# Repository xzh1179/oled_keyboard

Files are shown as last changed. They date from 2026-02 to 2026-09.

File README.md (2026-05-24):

# OLED Keyboard

A custom mechanical keyboard project featuring per-key OLED displays for dynamic legends, status information, and highly personalized layouts.

## Overview

OLED Keyboard is an experimental custom keyboard platform where each key can display its own icon, label, layer state, shortcut, or custom graphics.  
The goal of this project is to explore the intersection of keyboard design, multi-panel display integration, power distribution, and user interaction.

This project combines:

- custom PCB design
- embedded firmware development
- OLED display integration
- keyboard matrix scanning
- USB communication
- dynamic key rendering

Depending on the firmware mode, each key can show:

- key labels
- shortcuts
- symbols
- macros
- layer indicators
- application-specific legends
- simple animations or status feedback

## Motivation

Traditional keyboards are static: the legend printed on a keycap never changes.  
This project explores a more flexible and expressive approach where each key can adapt visually to:

- active layer
- language layout
- software context
- macro profile
- user preferences

The idea is to make a keyboard that is not only functional, but also programmable, informative, and visually unique.

## Features

- Per-key OLED displays
- Fully custom PCB
- Mechanical key switches
- Dynamic legends and layer indication
- Custom embedded firmware
- USB connectivity
- Macro and shortcut support
- Potential support for animations and contextual UI

## Hardware

Current hardware exploration includes:

- microcontroller: RP2040 
- OLED display 0.64inch 64x64 pixels, RGB color, based on SSD1357 controller 
- keyboard matrix scanning
- Kailh Choc V1 mechanical switch
- power distribution for many small displays
- SPI display communication
- optional rotary encoder support
- USB interface

> The exact hardware architecture may evolve as the project progresses.

## Architecture

The project is roughly divided into the following blocks:

1. **Keyboard matrix**  
   Detects key presses using rows and columns.

2. **Display subsystem**  
   Drives the OLED displays and refreshes per-key content.

3. **Firmware layer engine**  
   Handles keymaps, layers, macros, and display content generation.

4. **USB HID interface**  
   Sends keyboard events to the host computer.

5. **Power management**  
   Ensures stable power delivery for the MCU, switches, and all displays.

## Challenges

This project involves several interesting engineering challenges:

- driving many OLED displays efficiently
- balancing refresh rate and power consumption
- routing high-density display interconnects on PCB while keeping the layout compact, especially do not create too large space between two keys
- scaling SPI/I2C buses
- memory usage for icons/fonts/framebuffers
- firmware architecture for real-time input + rendering
- mechanical integration and assembly

## Project Status

This project is currently in active development.

Current focus areas include:

- hardware architecture exploration
- PCB design
- display driving strategy
- firmware prototyping
- validation of power and signal integrity constraints

## Repository Structure

```text
.
├── docs/            # Design notes, architecture, ideas, references
├── hardware/        # Schematics, PCB files, manufacturing outputs
├── firmware/        # Embedded firmware source code
├── images/          # Photos, renders, screenshots, diagrams
├── tools/           # Helper scripts, generators, utilities
└── README.md
```

## Assembly
The initial assembly of the keyboard is shown in the two figures below. At this stage, only one screen and one mechanical switch were mounted 
in order to validate the basic functionalities before proceeding with the soldering of the remaining components.

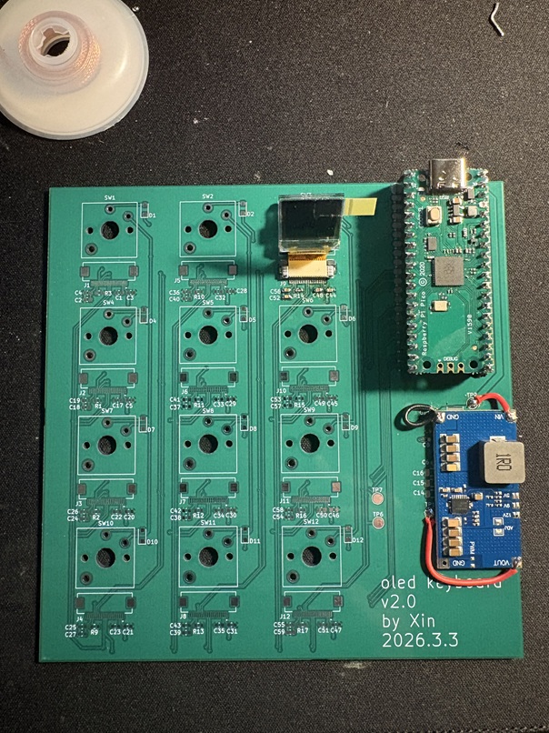
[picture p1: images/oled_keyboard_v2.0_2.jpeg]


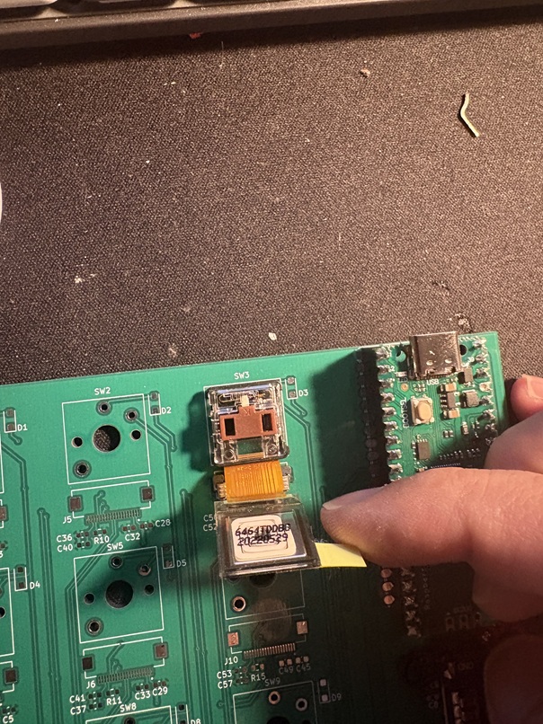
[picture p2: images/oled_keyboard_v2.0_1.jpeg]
 

Initial assembly has been completed. Functional testing will be conducted in the next stage.

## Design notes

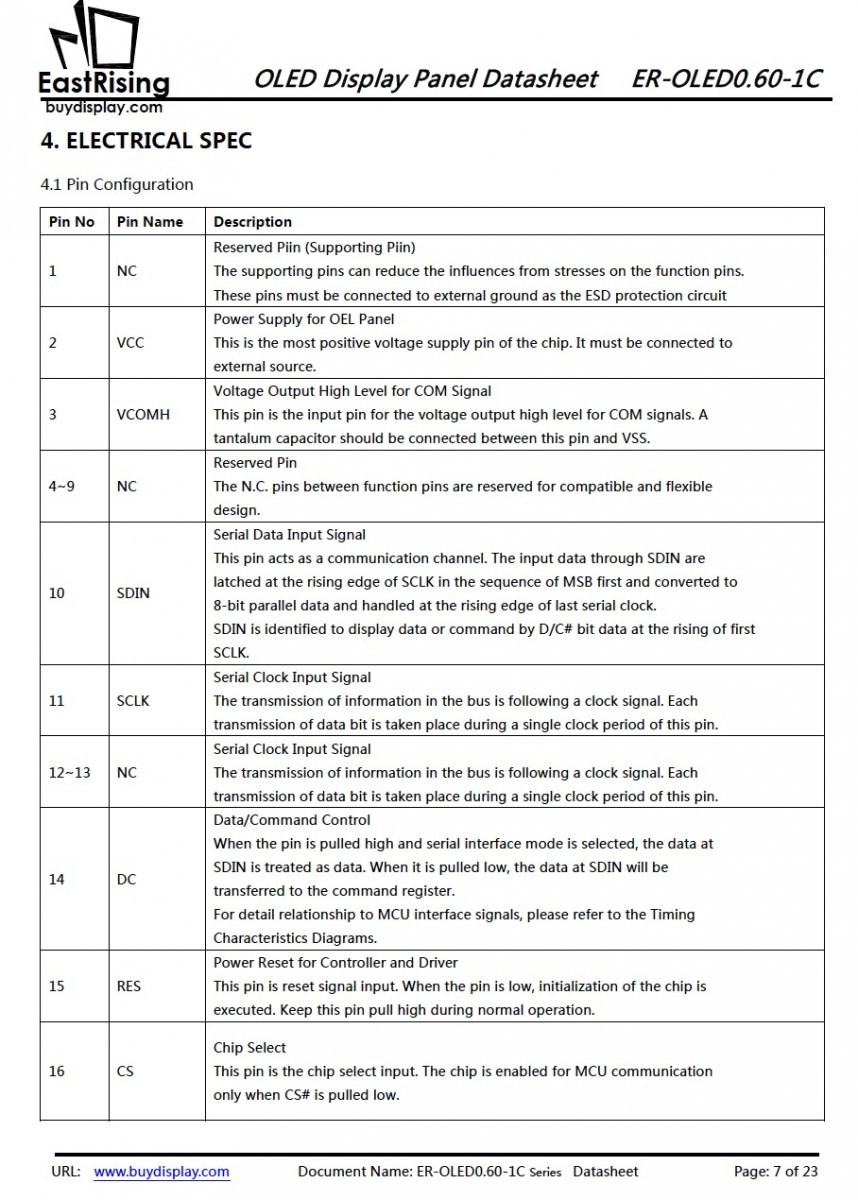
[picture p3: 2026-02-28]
doc/Screenshot 2024-11-09 at 2.21.43 AM.jpg

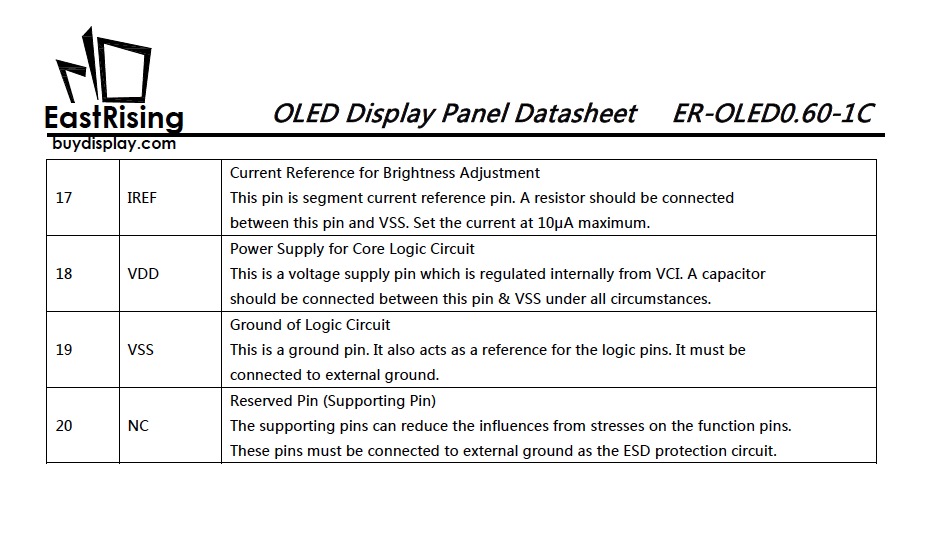
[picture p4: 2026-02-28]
doc/Screenshot 2024-11-09 at 2.21.47 AM.jpg

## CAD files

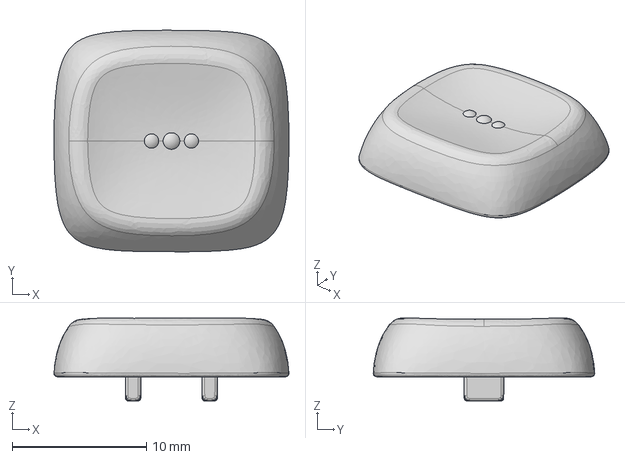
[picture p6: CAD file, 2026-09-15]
Choc_Stem_Choc_Size_Normal_Homing.step
17.5 x 16.5 x 6.17 mm

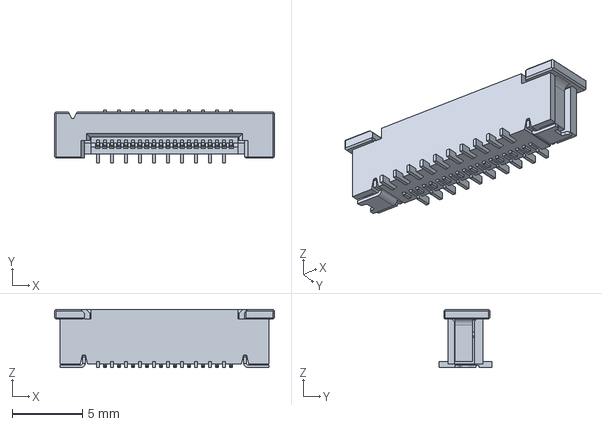
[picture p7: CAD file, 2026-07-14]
components/20pin_conn_vert/2-1734742-0.step
15.7 x 3.80 x 4.15 mm

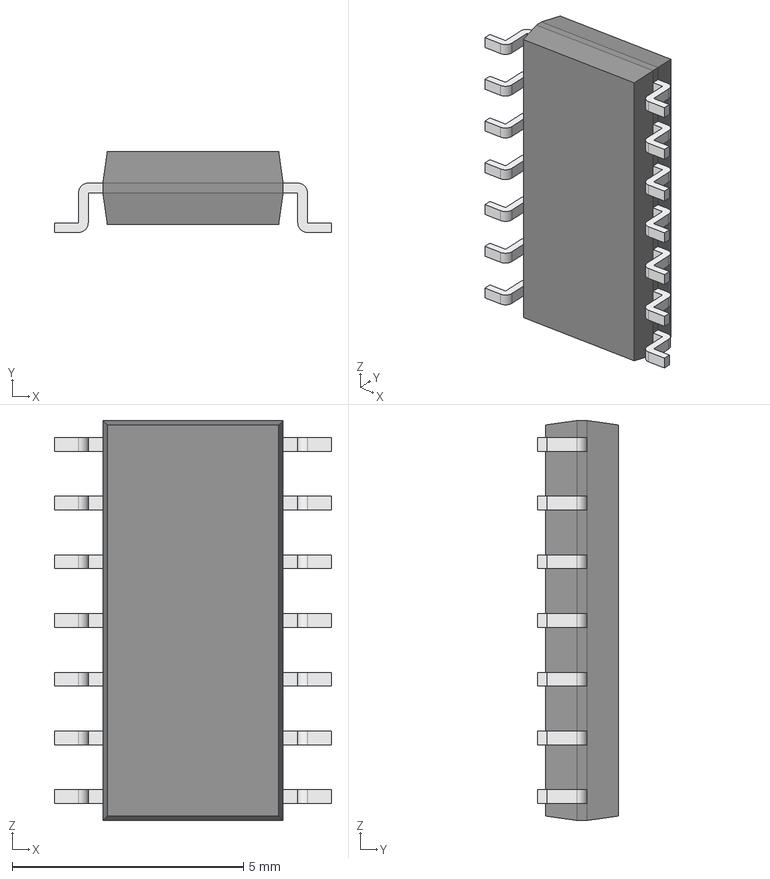
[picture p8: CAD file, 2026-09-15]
components/SN74LVC125ADTG4/SN74LVC125ADTG4.step
6.00 x 1.75 x 8.65 mm
Body001 (Mirror #1) x 7
XY-plane x 12
X-axis x 12

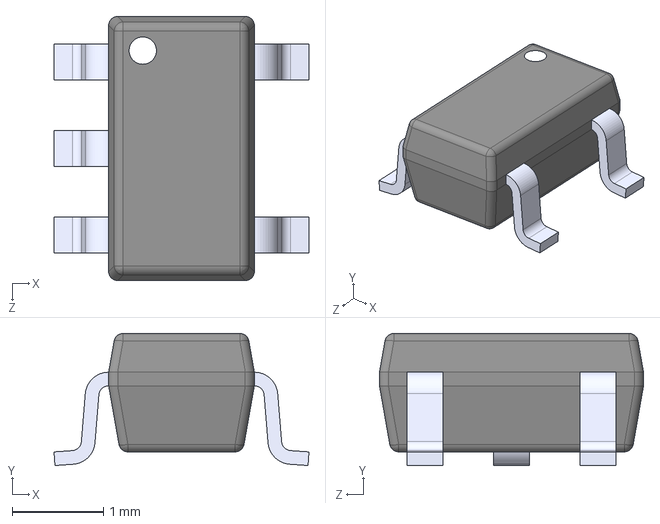
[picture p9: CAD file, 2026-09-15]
components/SN74LVC1G125DBVT/SN74LVC1G125DBVT.step
2.80 x 1.45 x 2.90 mm

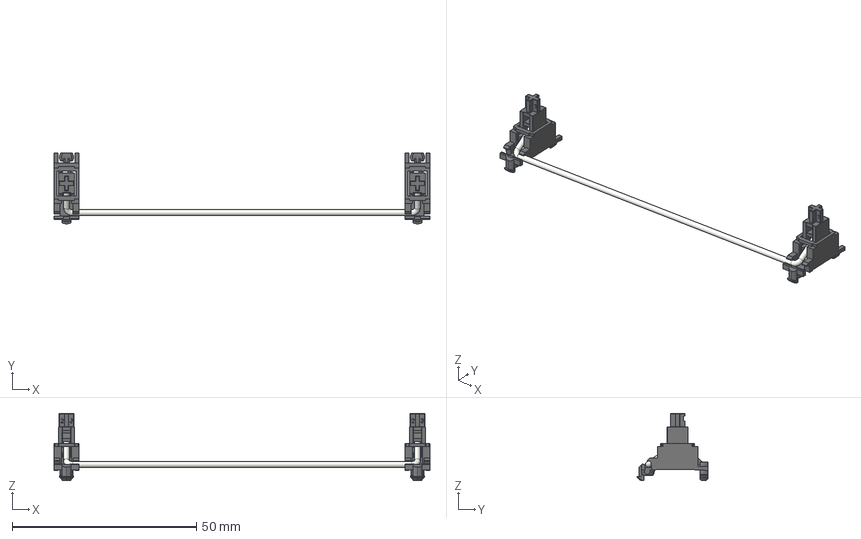
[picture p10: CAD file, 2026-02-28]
kiswitch-main/kiswitch-main/source_3d/Mounting_Keyboard_Stabilizer/Stabilizer_Cherry_MX_6u.FCStd
102.1 x 19.2 x 18.3 mm
Bar
Stabilizer_Key_
Stabilizer_Base_
Stabilizer_Key
Stabilizer_Base

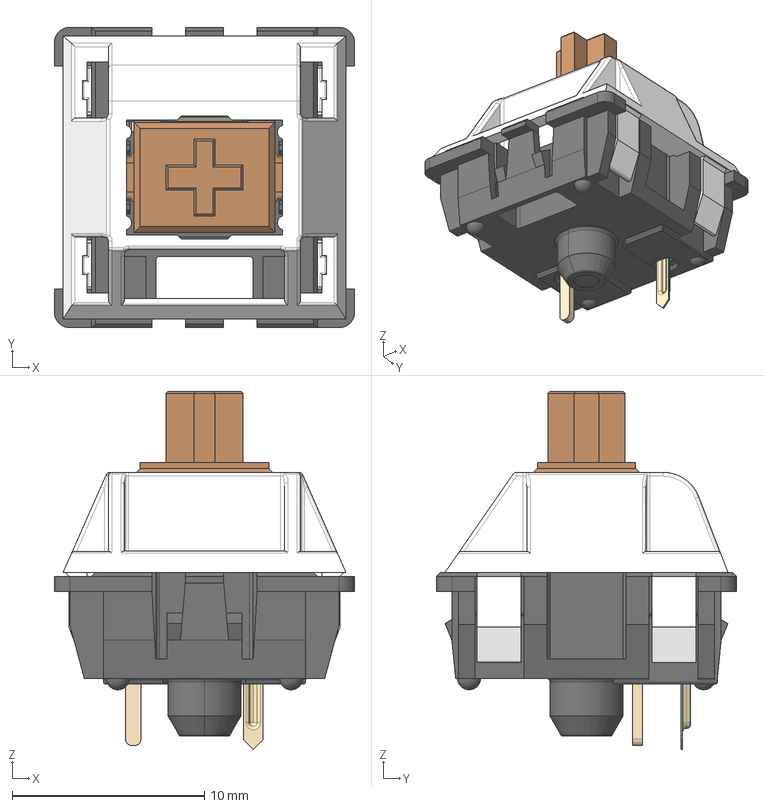
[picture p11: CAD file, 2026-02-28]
kiswitch-main/kiswitch-main/source_3d/Switch_Keyboard_Cherry_MX/SW_Cherry_MX_Plate.FCStd
15.6 x 15.6 x 18.6 mm
Lower_Housing
Upper_Housing
Stem
Pin_1
Pin_2
Spring
Clicker

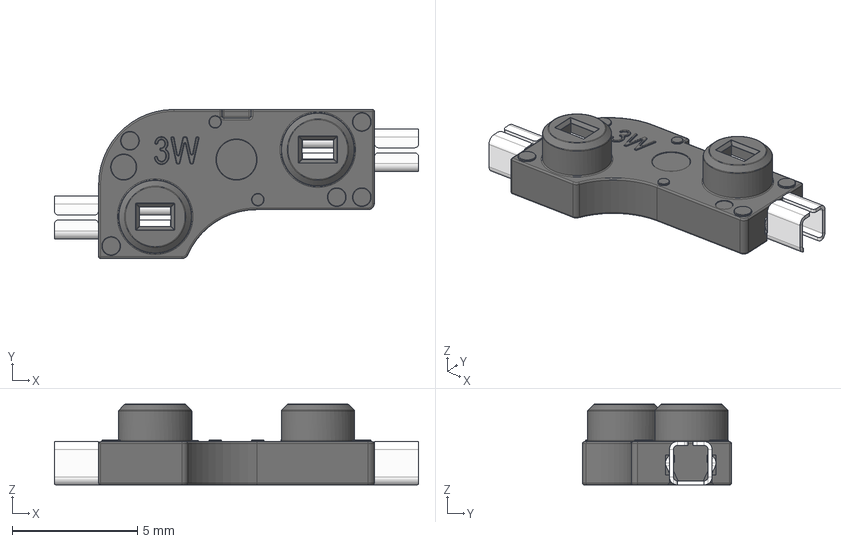
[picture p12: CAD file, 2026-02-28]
kiswitch-main/kiswitch-main/source_3d/Switch_Keyboard_Kailh/SW_Hotswap_Kailh.FCStd
14.5 x 5.95 x 3.22 mm
Pin_1
Pin_2
Plastic

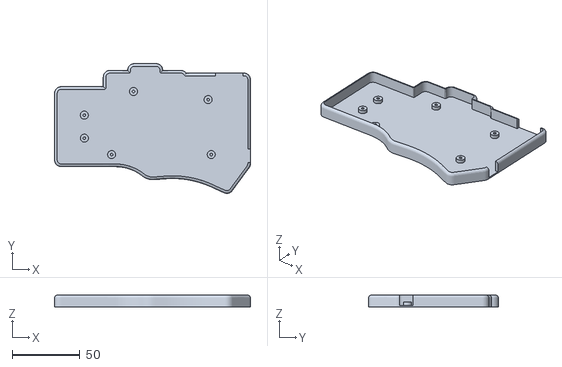
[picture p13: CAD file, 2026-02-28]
samples/piantor/piantor-main/case/bottom.stl
144.8 x 95.9 x 8.60

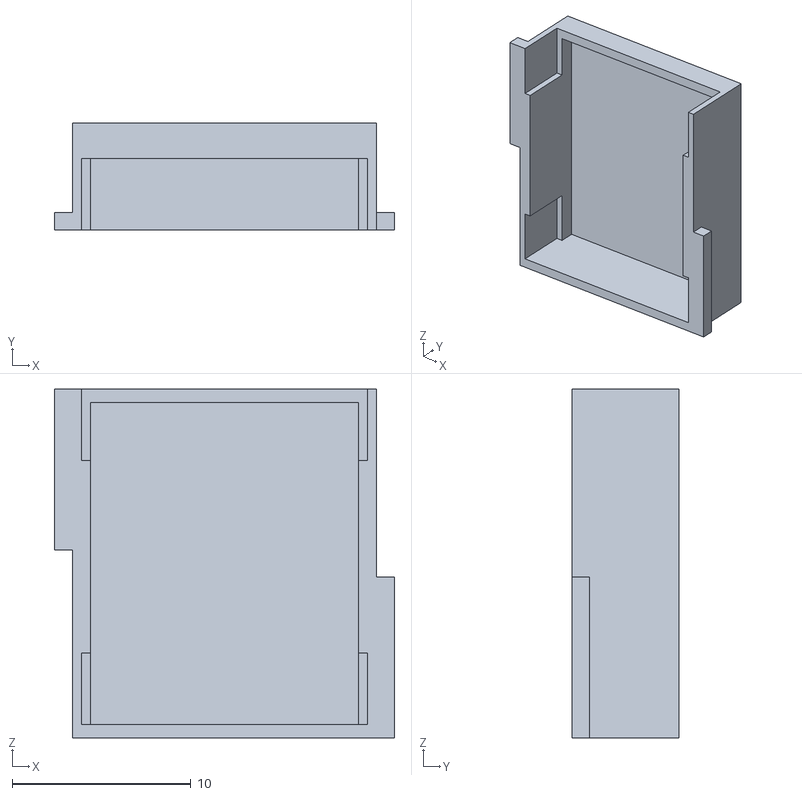
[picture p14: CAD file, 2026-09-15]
shell/shell - key-1.STL
19.0 x 6.00 x 19.5

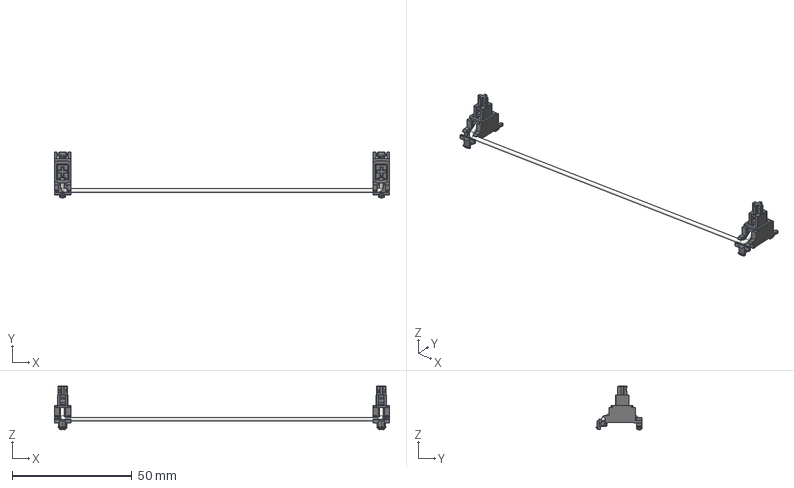
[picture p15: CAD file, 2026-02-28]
kiswitch-main/kiswitch-main/source_3d/Mounting_Keyboard_Stabilizer/Stabilizer_Cherry_MX_8u.FCStd
140.1 x 19.2 x 18.3 mm
Bar
Stabilizer_Key_
Stabilizer_Base_
Stabilizer_Key
Stabilizer_Base

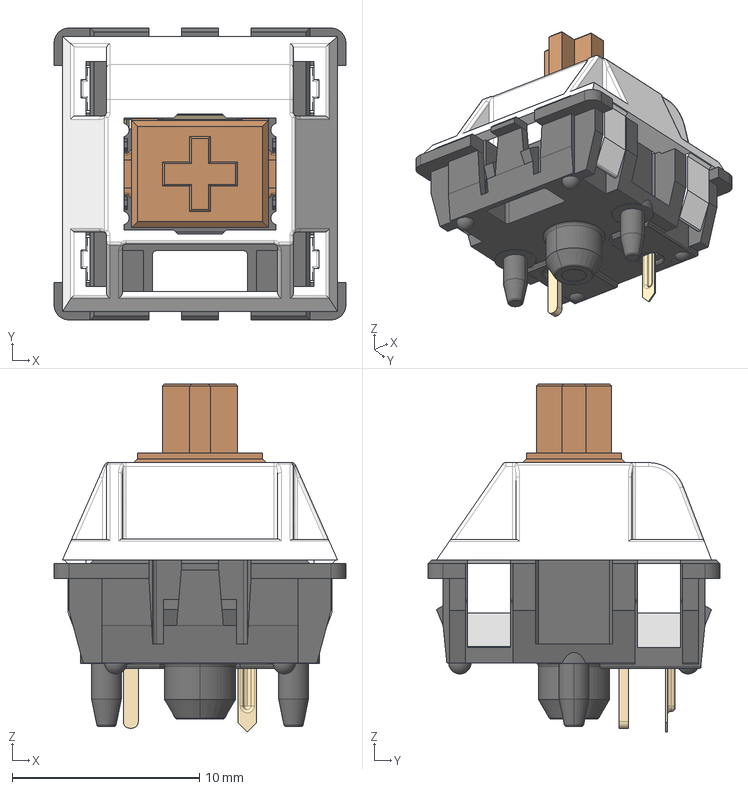
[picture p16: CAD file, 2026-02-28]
kiswitch-main/kiswitch-main/source_3d/Switch_Keyboard_Cherry_MX/SW_Cherry_MX_PCB.FCStd
15.6 x 15.6 x 18.6 mm
Lower_Housing
Upper_Housing
Stem
Pin_1
Pin_2
Spring
Clicker

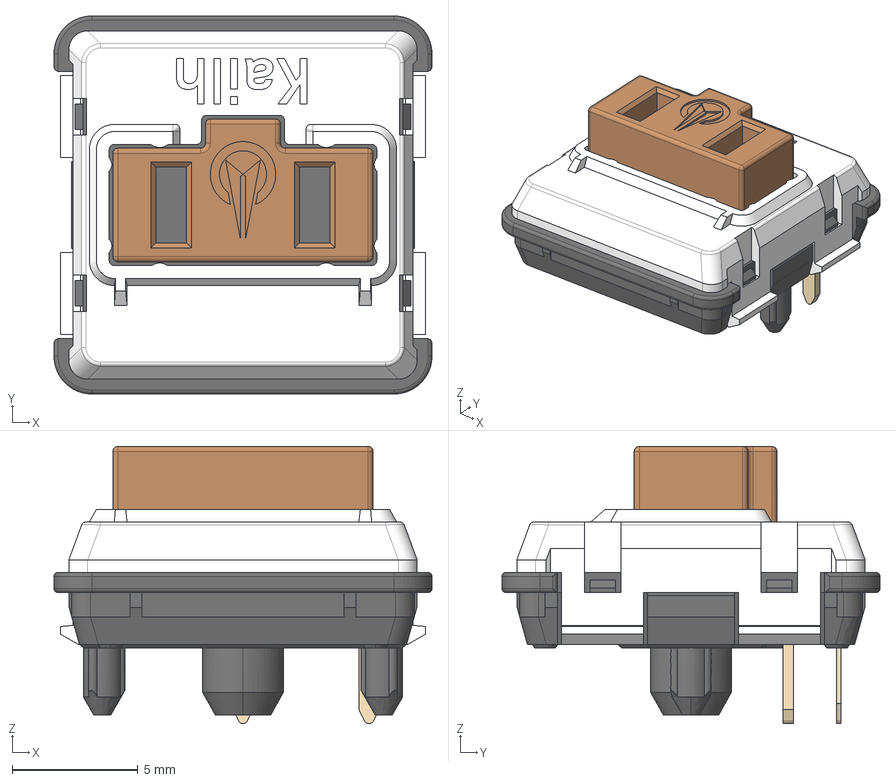
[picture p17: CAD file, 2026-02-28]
kiswitch-main/kiswitch-main/source_3d/Switch_Keyboard_Kailh/SW_Kailh_Choc_V1.FCStd
15.0 x 15.0 x 11.0 mm
Upper_Housing
Lower_Housing
Stem
Pin_2
Pin_1

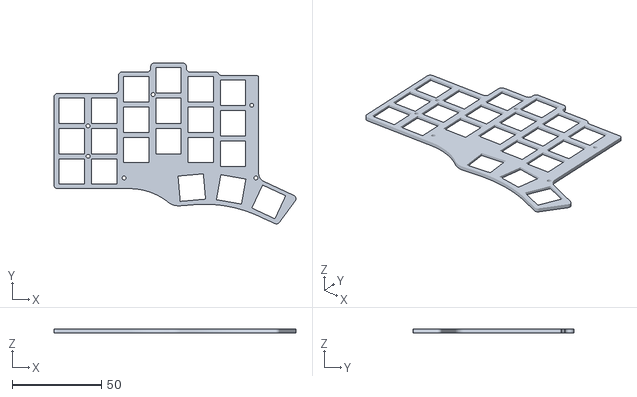
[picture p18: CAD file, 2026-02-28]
samples/piantor/piantor-main/case/switch-plate.stl
135.2 x 89.9 x 2.00

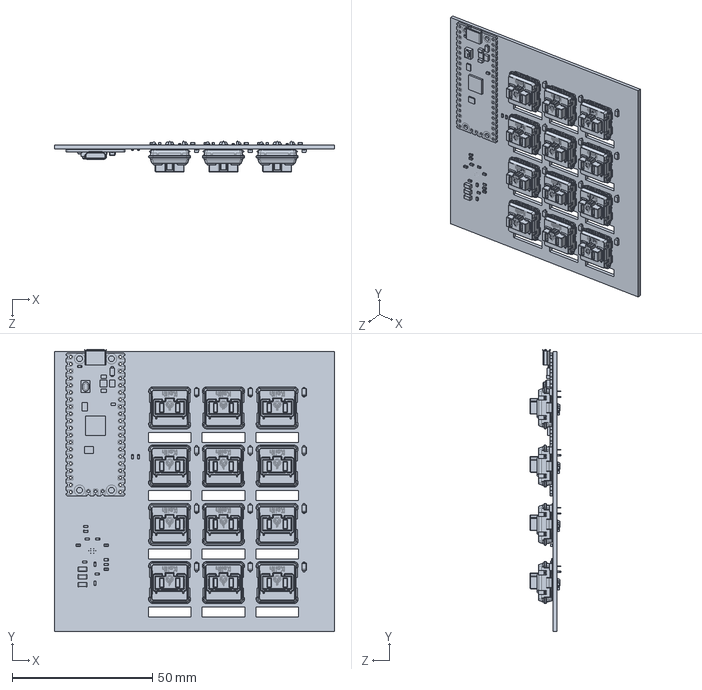
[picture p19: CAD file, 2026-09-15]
shell/pcb.SLDPRT
100.0 x 100.8 x 11.0 mm

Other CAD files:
shell/Assem1.SLDASM
kiswitch-main/kiswitch-main/source_3d/Mounting_Keyboard_Stabilizer/Stabilizer_Cherry_MX_7u.FCStd
kiswitch-main/kiswitch-main/source_3d/Switch_Keyboard_Kailh/SW_Hotswap_Kailh_Choc_v1.FCStd
shell/cover.SLDPRT
components/tps61088/TPS61088RHLR.step
kiswitch-main/kiswitch-main/source_3d/Mounting_Keyboard_Stabilizer/Stabilizer_Cherry_MX_2u.FCStd
kiswitch-main/kiswitch-main/source_3d/Mounting_Keyboard_Stabilizer/Stabilizer_Cherry_MX_3u.FCStd
kiswitch-main/kiswitch-main/source_3d/Mounting_Keyboard_Stabilizer/Stabilizer_Cherry_MX_6.25u.FCStd
shell/bottom.SLDPRT
shell/display_support.SLDPRT
shell/display_support.STL
shell/key.SLDPRT
shell/oled_keyboard.SLDASM
shell/oled_keyboard.step
shell/shell - cover-1 - bottom-1.STL
shell/shell - cover-1 - cover-1.STL

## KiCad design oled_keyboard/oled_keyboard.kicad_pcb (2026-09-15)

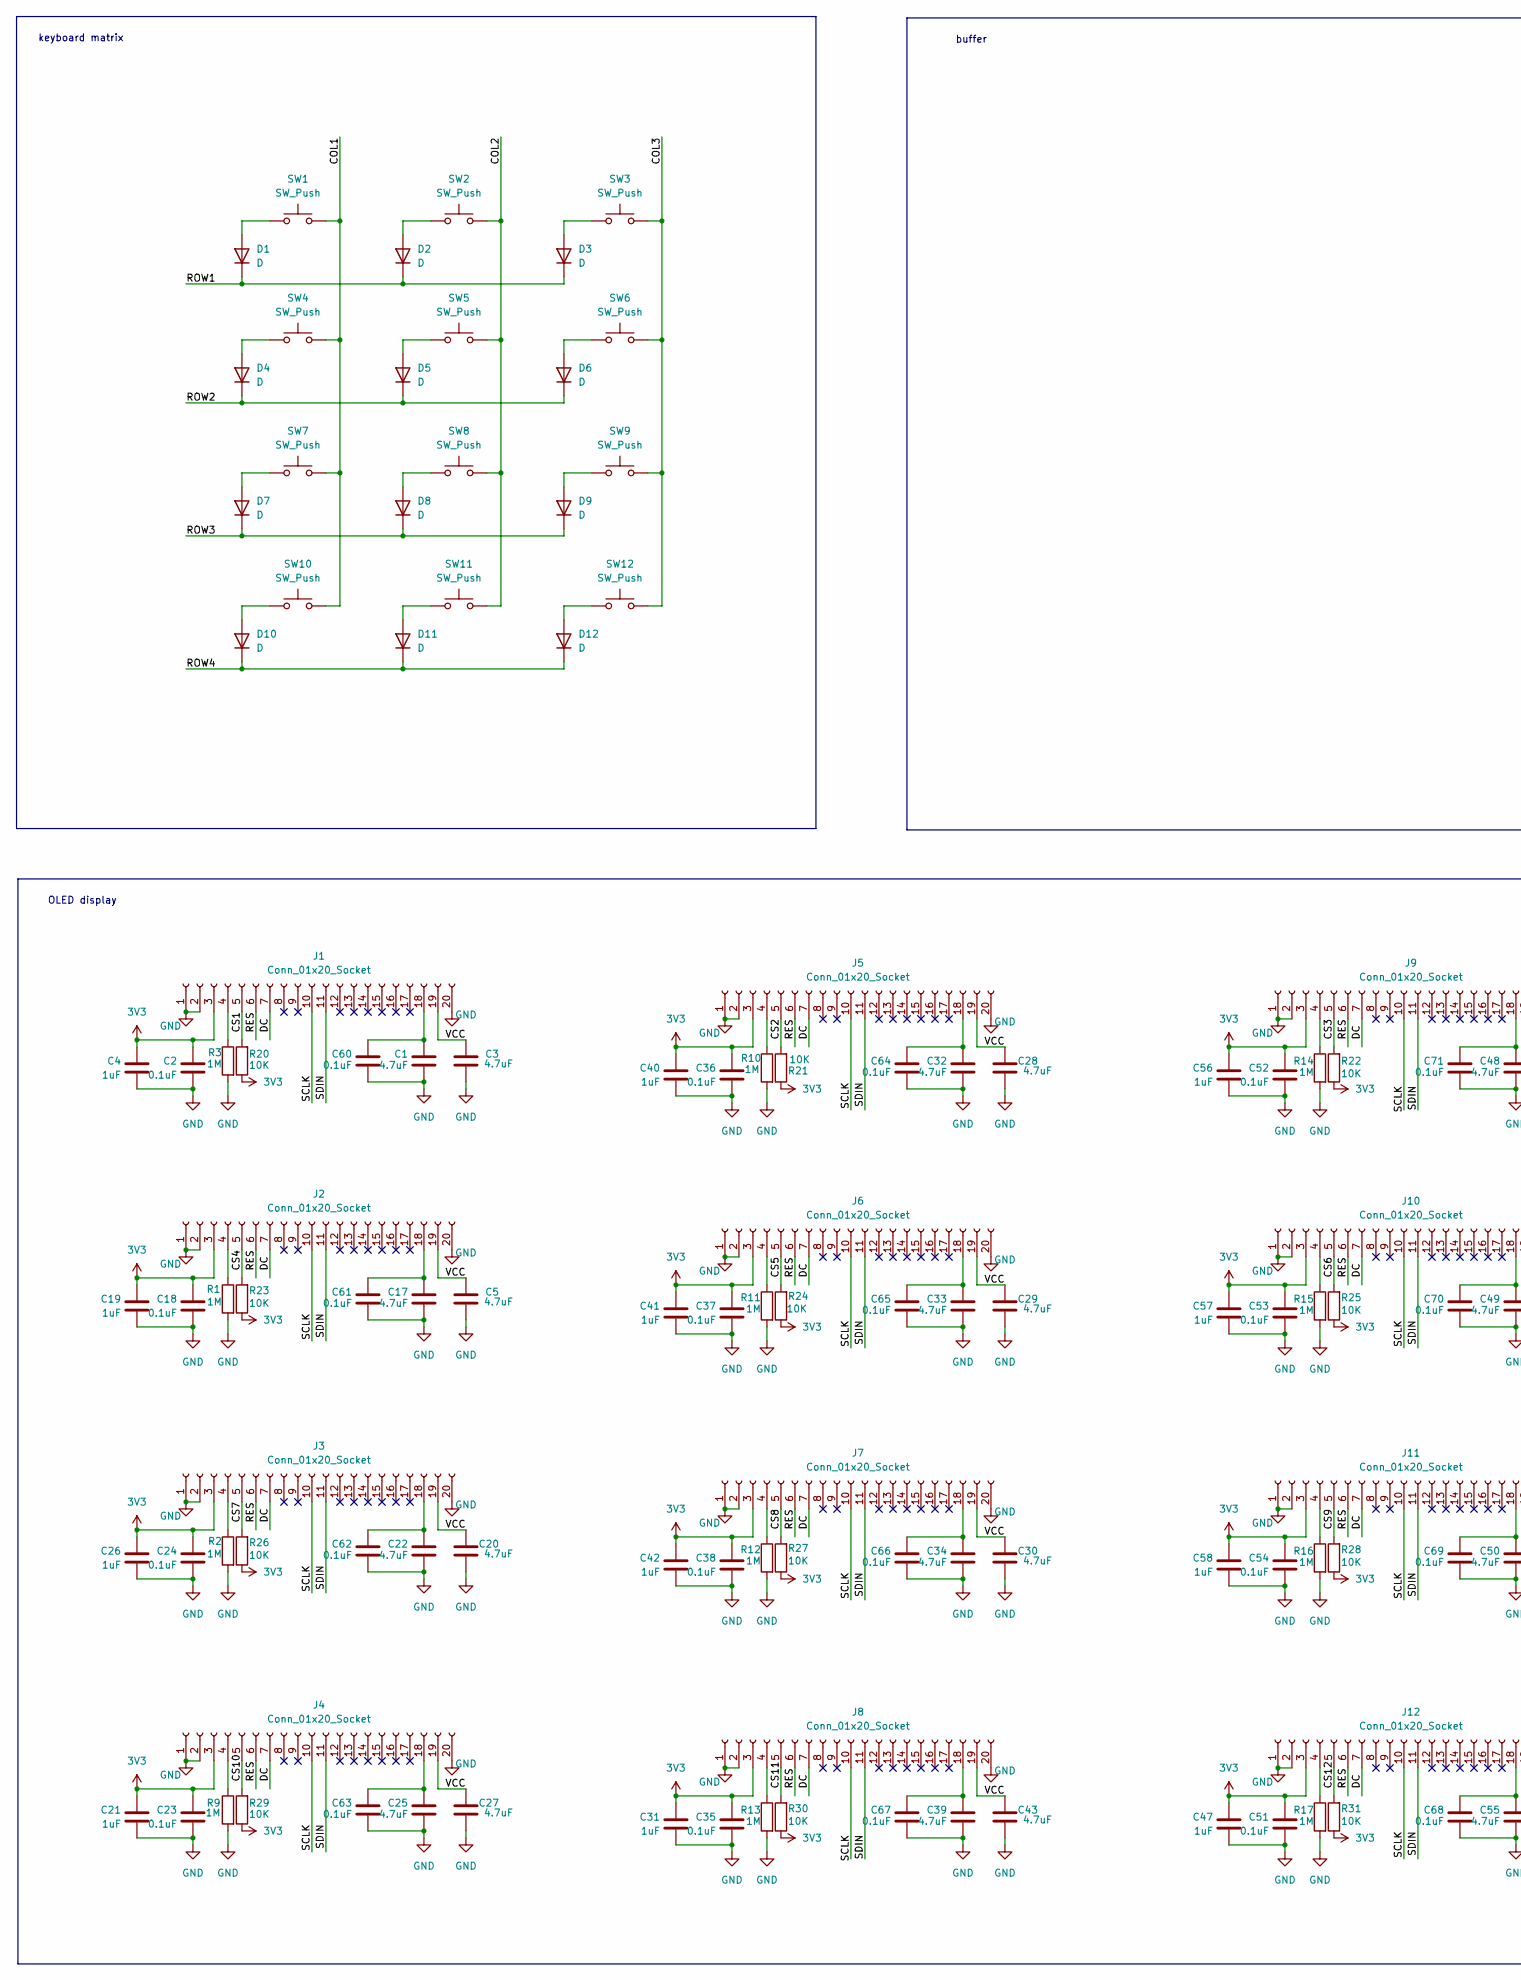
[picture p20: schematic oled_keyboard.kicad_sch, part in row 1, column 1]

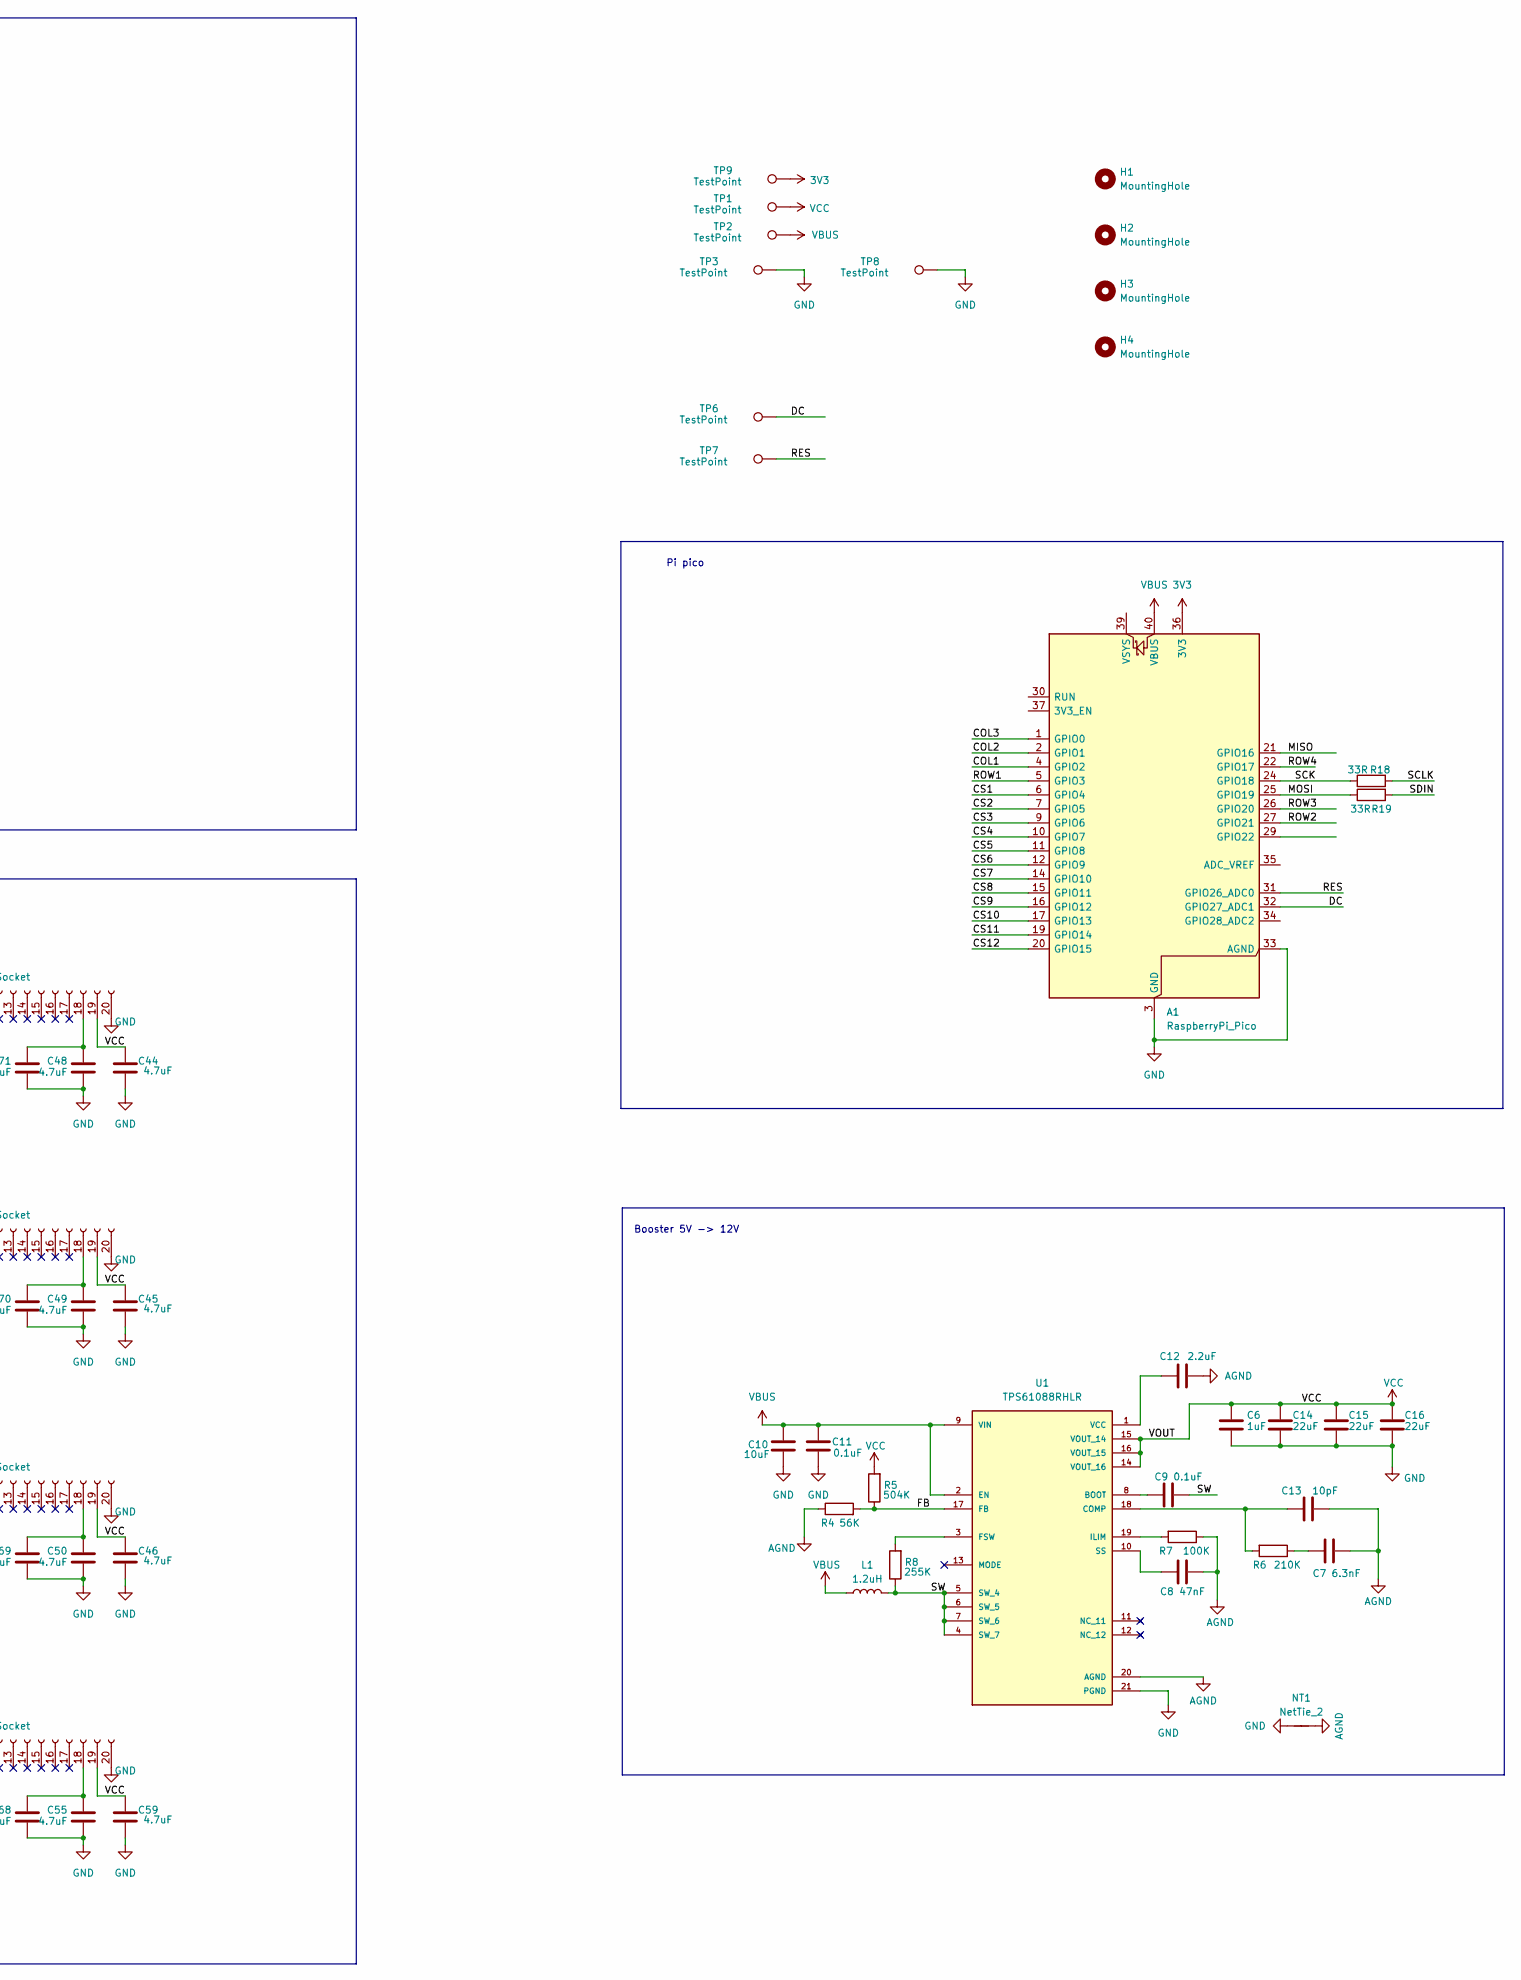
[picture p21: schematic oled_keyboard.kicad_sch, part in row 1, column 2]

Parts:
A1: RaspberryPi_Pico; RaspberryPi_Pico_Common_Unspecified
C1, C3, C5, C17, C20, C22, C25, C27, C28, C29, C30, C32, C33, C34, C39, C43, C44, C45, C46, C48, C49, C50, C55, C59: 4.7uF; C_0603_1608Metric
C2, C9, C11, C18, C23, C24, C35, C36, C37, C38, C51, C52, C53, C54, C60, C61, C62, C63, C64, C65, C66, C67, C68, C69, C70, C71: 0.1uF; C_0603_1608Metric
C4, C6, C19, C21, C26, C31, C40, C41, C42, C47, C56, C57, C58: 1uF; C_0603_1608Metric
C7: 6.3nF; C_0603_1608Metric
C8: 47nF; C_0603_1608Metric
C10: 10uF; C_0603_1608Metric
C12: 2.2uF; C_0603_1608Metric
C13: 10pF; C_0603_1608Metric
C14, C15, C16: 22uF; C_1206_3216Metric
D1, D2, D3, D4, D5, D6, D7, D8, D9, D10, D11, D12: D; D_SOD-123F
H1, H2, H3, H4: MountingHole; MountingHole_2.7mm_M2.5
J1, J2, J3, J4, J5, J6, J7, J8, J9, J10, J11, J12: Conn_01x20_Socket; TE_2-1734742-0
L1: 1.2uH; L_Taiyo-Yuden_MD-4040
NT1: NetTie_2; NetTie-2_SMD_Pad0.5mm
R1, R2, R3, R9, R10, R11, R12, R13, R14, R15, R16, R17: 1M; R_0603_1608Metric
R4: 56K; R_0603_1608Metric
R5: 504K; R_0603_1608Metric
R6: 210K; R_0603_1608Metric
R7: 100K; R_0603_1608Metric
R8: 255K; R_0603_1608Metric
R18, R19: 33R; R_0603_1608Metric
R20, R21, R22, R23, R24, R25, R26, R27, R28, R29, R30, R31: 10K; R_0603_1608Metric
SW1, SW2, SW3, SW4, SW5, SW6, SW7, SW8, SW9, SW10, SW11, SW12: SW_Push; SW_Kailh_Choc_V1V2
TP1, TP2, TP3, TP6, TP7, TP8, TP9: TestPoint; TestPoint_Pad_D2.5mm
U1: TPS61088RHLR; IC_TPS61088RHLR; PARTREV 4219071/A 05/2017

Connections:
3V3: A1.36 (3V3), C2.1, C4.1, C18.1, C19.1, C21.1, C23.1, C24.1, C26.1, C31.1, C35.1, C36.1, C37.1, C38.1, C40.1, C41.1, C42.1, C47.1, C51.1, C52.1, C53.1, C54.1, C56.1, C57.1, C58.1, J1.3, J2.3, J3.3, J4.3, J5.3, J6.3, J7.3, J8.3, J9.3, J10.3, J11.3, J12.3, R20.1, R21.1, R22.1, R23.1, R24.1, R25.1, R26.1, R27.1, R28.1, R29.1, R30.1, R31.1, TP9.1 (1_1)
/COL1: A1.4 (GPIO2), SW1.2, SW4.2, SW7.2, SW10.2
/COL2: A1.2 (GPIO1), SW2.2, SW5.2, SW8.2, SW11.2
/COL3: A1.1 (GPIO0), SW3.2, SW6.2, SW9.2, SW12.2
/CS1: A1.6 (GPIO4), J1.5, R20.2
/CS2: A1.7 (GPIO5), J5.5, R21.2
/CS3: A1.9 (GPIO6), J9.5, R22.2
/CS4: A1.10 (GPIO7), J2.5, R23.2
/CS5: A1.11 (GPIO8), J6.5, R24.2
/CS6: A1.12 (GPIO9), J10.5, R25.2
/CS7: A1.14 (GPIO10), J3.5, R26.2
/CS8: A1.15 (GPIO11), J7.5, R27.2
/CS9: A1.16 (GPIO12), J11.5, R28.2
/CS10: A1.17 (GPIO13), J4.5, R29.2
/CS11: A1.19 (GPIO14), J8.5, R30.2
/CS12: A1.20 (GPIO15), J12.5, R31.2
/DC: A1.32 (GPIO27_ADC1), J1.7, J2.7, J3.7, J4.7, J5.7, J6.7, J7.7, J8.7, J9.7, J10.7, J11.7, J12.7, TP6.1 (1_1)
/FB: R4.2, R5.1, U1.17 (FB)
/MISO: A1.21 (GPIO16)
/MOSI: A1.25 (GPIO19), R19.1
/RES: A1.31 (GPIO26_ADC0), J1.6, J2.6, J3.6, J4.6, J5.6, J6.6, J7.6, J8.6, J9.6, J10.6, J11.6, J12.6, TP7.1 (1_1)
/ROW1: A1.5 (GPIO3), D1.1 (K), D2.1 (K), D3.1 (K)
/ROW2: A1.27 (GPIO21), D4.1 (K), D5.1 (K), D6.1 (K)
/ROW3: A1.26 (GPIO20), D7.1 (K), D8.1 (K), D9.1 (K)
/ROW4: A1.22 (GPIO17), D10.1 (K), D11.1 (K), D12.1 (K)
/SCK: A1.24 (GPIO18), R18.1
/SCLK: J1.10, J2.10, J3.10, J4.10, J5.10, J6.10, J7.10, J8.10, J9.10, J10.10, J11.10, J12.10, R18.2
/SDIN: J1.11, J2.11, J3.11, J4.11, J5.11, J6.11, J7.11, J8.11, J9.11, J10.11, J11.11, J12.11, R19.2
/SW: C9.2, L1.2, R8.1, U1.4 (SW_7), U1.5 (SW_4), U1.6 (SW_5), U1.7 (SW_6)
AGND: C7.2, C8.2, C12.2, C13.2, NT1.1, R4.1, R7.1, U1.20 (AGND)
GND: A1.3 (GND), A1.8 (GND), A1.13 (GND), A1.18 (GND), A1.23 (GND), A1.28 (GND), A1.33 (AGND), A1.38 (GND), C1.2, C2.2, C3.2, C4.2, C5.2, C6.2, C10.1, C11.1, C14.2, C15.2, C16.2, C17.2, C18.2, C19.2, C20.2, C21.2, C22.2, C23.2, C24.2, C25.2, C26.2, C27.2, C28.2, C29.2, C30.2, C31.2, C32.2, C33.2, C34.2, C35.2, C36.2, C37.2, C38.2, C39.2, C40.2, C41.2, C42.2, C43.2, C44.2, C45.2, C46.2, C47.2, C48.2, C49.2, C50.2, C51.2, C52.2, C53.2, C54.2, C55.2, C56.2, C57.2, C58.2, C59.2, C60.2, C61.2, C62.2, C63.2, C64.2, C65.2, C66.2, C67.2, C68.2, C69.2, C70.2, C71.2, J1.1, J1.2, J1.20, J2.1, J2.2, J2.20, J3.1, J3.2, J3.20, J4.1, J4.2, J4.20, J5.1, J5.2, J5.20, J6.1, J6.2, J6.20, J7.1, J7.2, J7.20, J8.1, J8.2, J8.20, J9.1, J9.2, J9.20, J10.1, J10.2, J10.20, J11.1, J11.2, J11.20, J12.1, J12.2, J12.20, NT1.2, R1.2, R2.2, R3.2, R9.2, R10.2, R11.2, R12.2, R13.2, R14.2, R15.2, R16.2, R17.2, TP3.1 (1_1), TP8.1 (1_1), U1.21 (PGND), U1.22 (PGND), U1.23 (PGND), U1.24 (PGND), U1.25 (PGND), U1.26 (PGND), U1.27 (PGND), U1.28 (PGND), U1.29 (PGND)
unnamed: C7.1, R6.1
unnamed: D1.2 (A), SW1.1
unnamed: D2.2 (A), SW2.1
unnamed: D3.2 (A), SW3.1
unnamed: D4.2 (A), SW4.1
unnamed: D5.2 (A), SW5.1
unnamed: D6.2 (A), SW6.1
unnamed: D7.2 (A), SW7.1
unnamed: D8.2 (A), SW8.1
unnamed: D9.2 (A), SW9.1
unnamed: D10.2 (A), SW10.1
unnamed: D11.2 (A), SW11.1
unnamed: D12.2 (A), SW12.1
unnamed: J1.4, R3.1
unnamed: C1.1, C60.1, J1.18
unnamed: J2.4, R1.1
unnamed: C17.1, C61.1, J2.18
unnamed: J3.4, R2.1
unnamed: C22.1, C62.1, J3.18
unnamed: J4.4, R9.1
unnamed: C25.1, C63.1, J4.18
unnamed: J5.4, R10.1
unnamed: C32.1, C64.1, J5.18
unnamed: J6.4, R11.1
unnamed: C33.1, C65.1, J6.18
unnamed: J7.4, R12.1
unnamed: C34.1, C66.1, J7.18
unnamed: J8.4, R13.1
unnamed: C39.1, C67.1, J8.18
unnamed: J9.4, R14.1
unnamed: C48.1, C71.1, J9.18
unnamed: J10.4, R15.1
unnamed: C49.1, C70.1, J10.18
unnamed: J11.4, R16.1
unnamed: C50.1, C69.1, J11.18
unnamed: J12.4, R17.1
unnamed: C55.1, C68.1, J12.18
unnamed: C9.1, U1.8 (BOOT)
unnamed: C13.1, R6.2, U1.18 (COMP)
unnamed: R8.2, U1.3 (FSW)
unnamed: R7.2, U1.19 (ILIM)
unnamed: C8.1, U1.10 (SS)
unnamed: C12.1, U1.1 (VCC)
VBUS: A1.40 (VBUS), C10.2, C11.2, L1.1, TP2.1 (1_1), U1.2 (EN), U1.9 (VIN)
VCC: C3.1, C5.1, C6.1, C14.1, C15.1, C16.1, C20.1, C27.1, C28.1, C29.1, C30.1, C43.1, C44.1, C45.1, C46.1, C59.1, J1.19, J2.19, J3.19, J4.19, J5.19, J6.19, J7.19, J8.19, J9.19, J10.19, J11.19, J12.19, R5.2, TP1.1 (1_1), U1.14 (VOUT_16), U1.15 (VOUT_14), U1.16 (VOUT_15)

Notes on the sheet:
buffer
OLED display
Pi pico
Booster 5V -> 12V
keyboard matrix

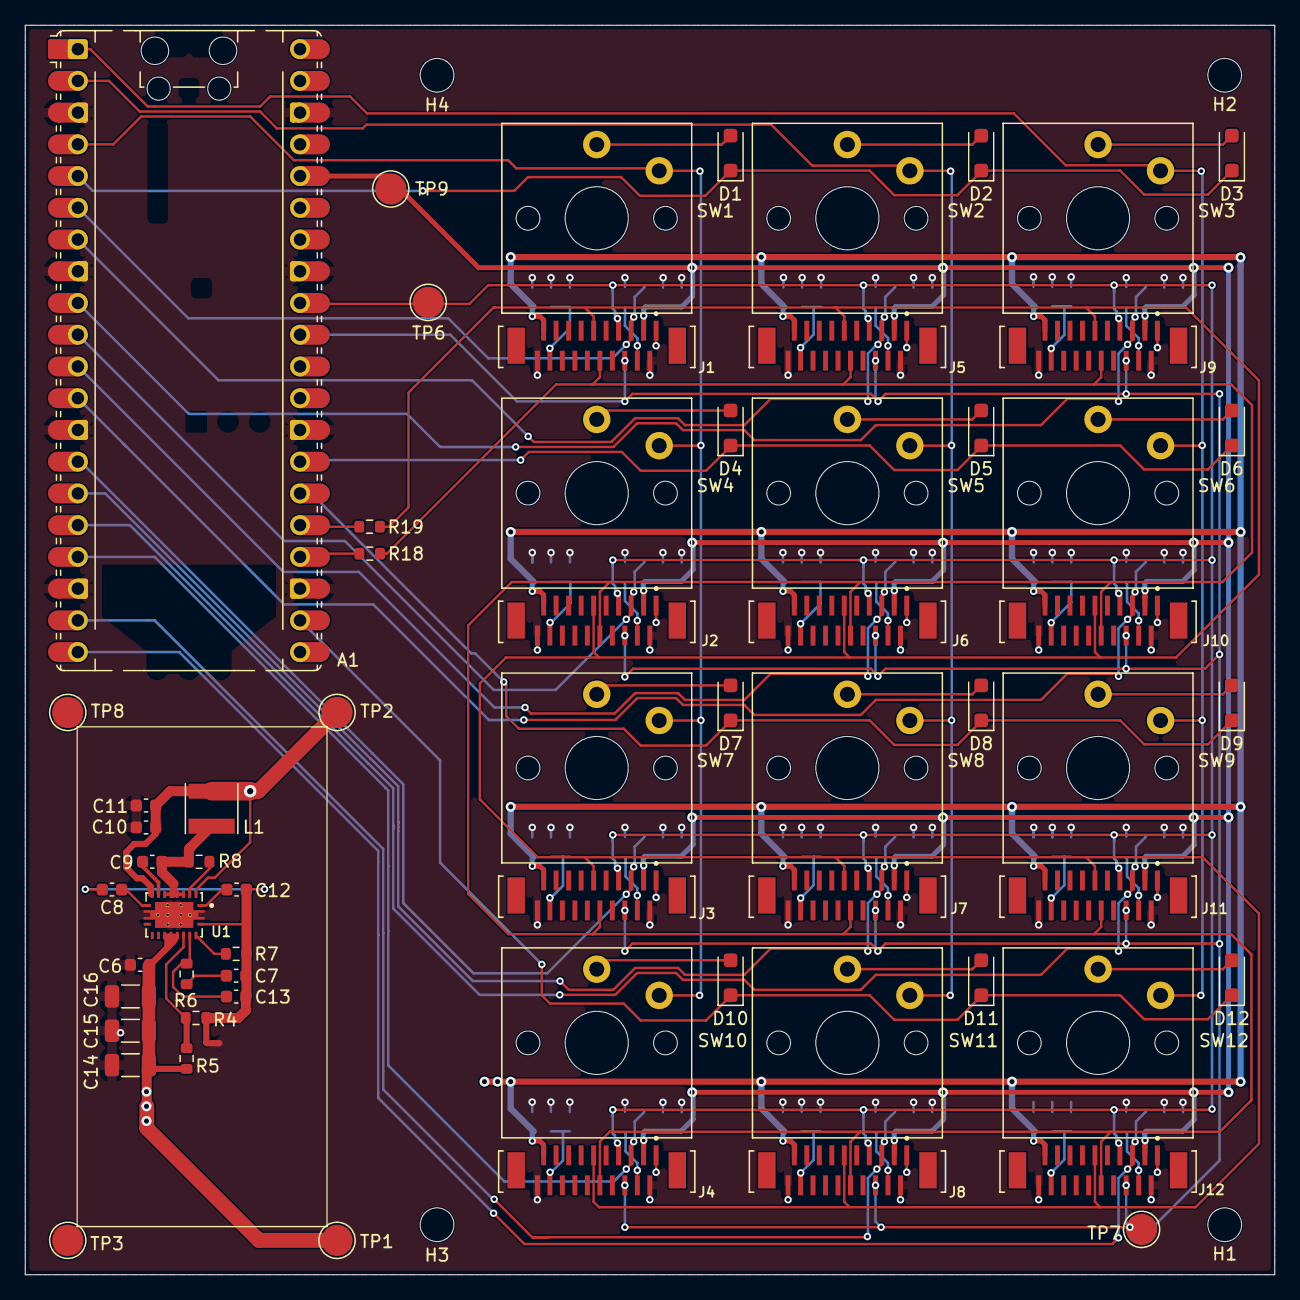
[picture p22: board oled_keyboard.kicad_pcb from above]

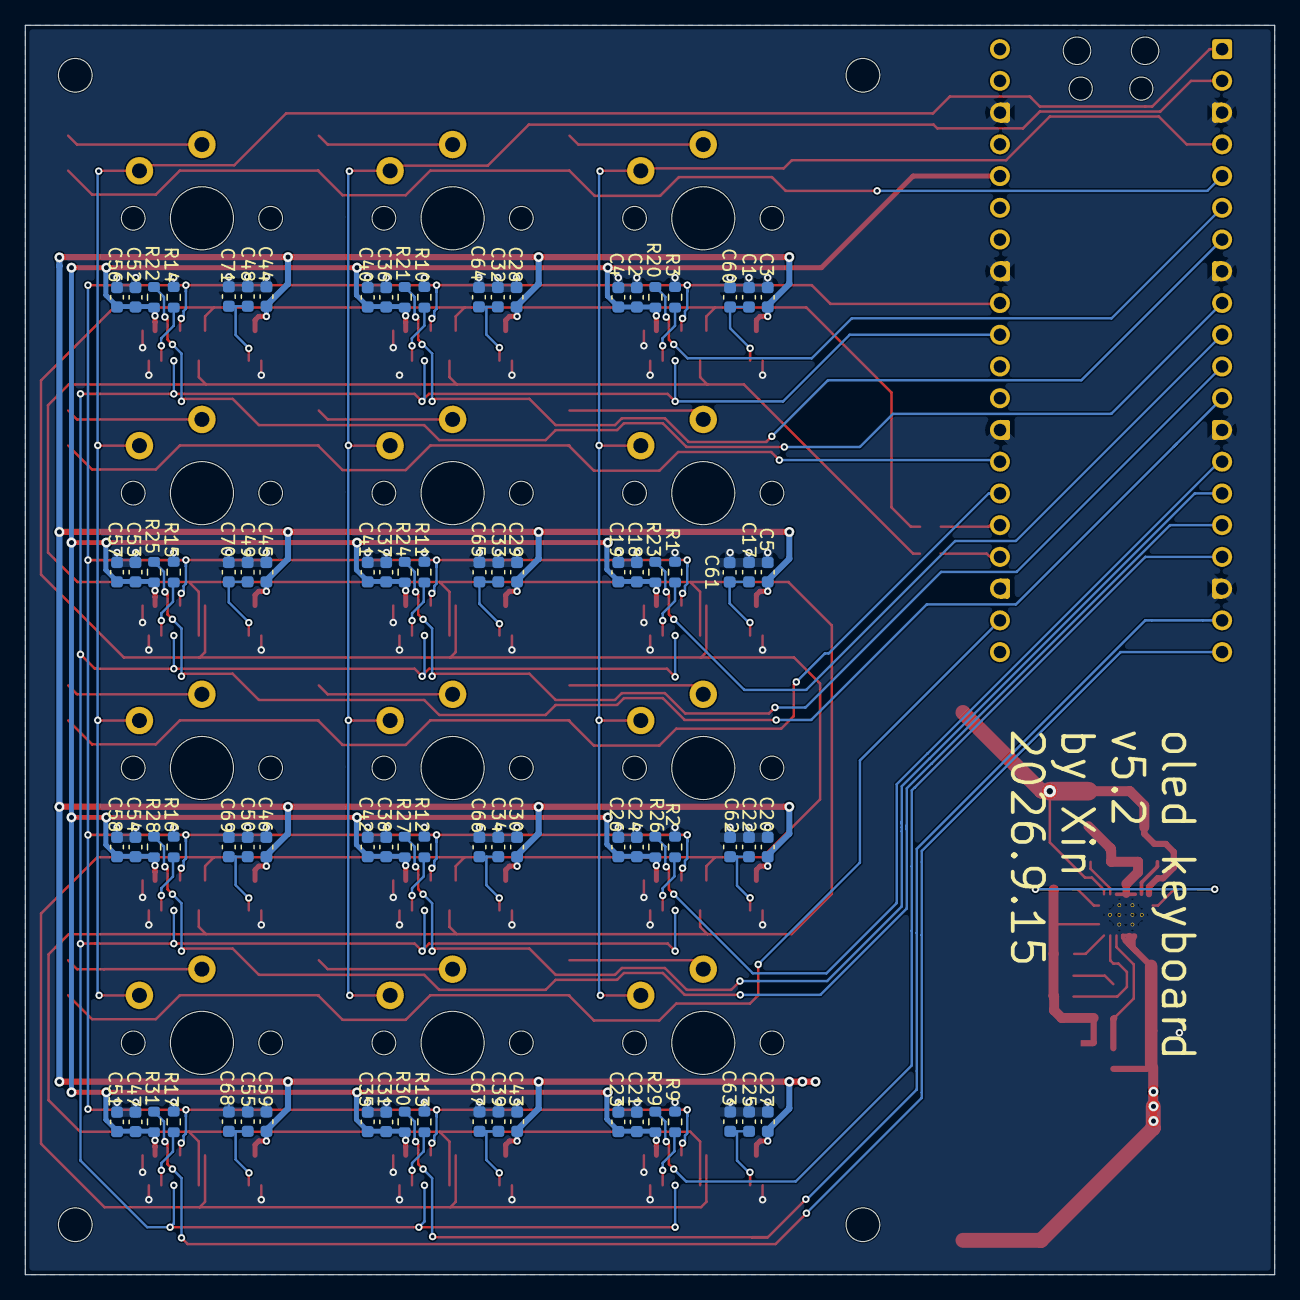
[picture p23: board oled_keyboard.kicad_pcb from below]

Board: 4 copper layers, 100.0 x 100.0 mm, 153 parts (84 on the bottom side), 75 nets.

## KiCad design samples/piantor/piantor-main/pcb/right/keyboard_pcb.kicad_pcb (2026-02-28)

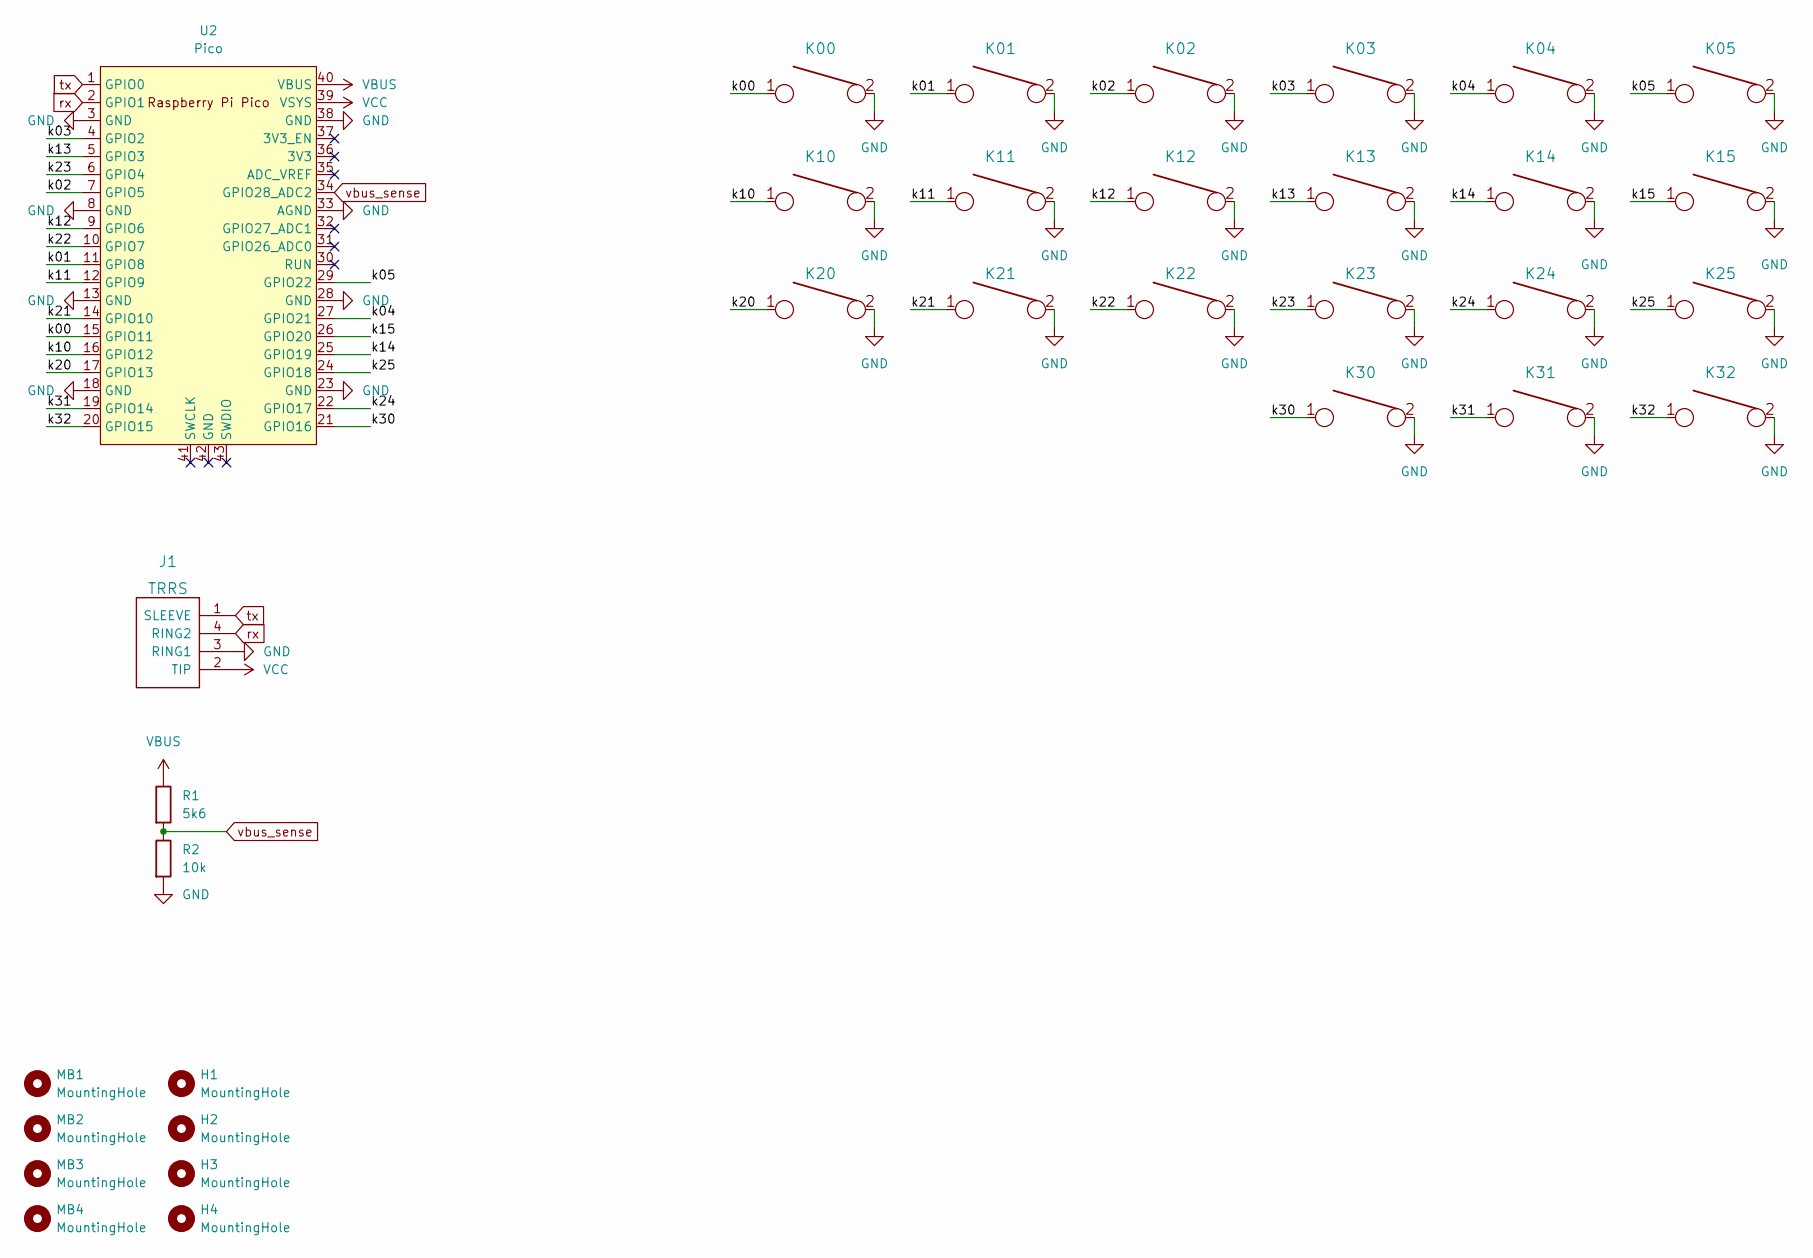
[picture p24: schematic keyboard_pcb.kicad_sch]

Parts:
H1, H2, H3, H4: MountingHole; MountingHole_2.2mm_M2-8mm
J1: TRRS; R_1206_3216Metric_Pad1.30x1.75mm_HandSolder
K00, K01, K02, K03, K04, K05, K10, K11, K12, K13, K14, K15, K20, K21, K22, K23, K24, K25, K30, K31, K32: KEYSW; SW_PG1350_reversible
MB1, MB2, MB3, MB4: MountingHole; mousebites
R1: 5k6; R_1206_3216Metric_Pad1.30x1.75mm_HandSolder
R2: 10k; R_1206_3216Metric_Pad1.30x1.75mm_HandSolder
U2: Pico; RPi_Pico_SMD_TH

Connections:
/k00: K00.1, U2.15 (GPIO11)
/k01: K01.1, U2.11 (GPIO8)
/k02: K02.1, U2.7 (GPIO5)
/k03: K03.1, U2.4 (GPIO2)
/k04: K04.1, U2.27 (GPIO21)
/k05: K05.1, U2.29 (GPIO22)
/k10: K10.1, U2.16 (GPIO12)
/k11: K11.1, U2.12 (GPIO9)
/k12: K12.1, U2.9 (GPIO6)
/k13: K13.1, U2.5 (GPIO3)
/k14: K14.1, U2.25 (GPIO19)
/k15: K15.1, U2.26 (GPIO20)
/k20: K20.1, U2.17 (GPIO13)
/k21: K21.1, U2.14 (GPIO10)
/k22: K22.1, U2.10 (GPIO7)
/k23: K23.1, U2.6 (GPIO4)
/k24: K24.1, U2.22 (GPIO17)
/k25: K25.1, U2.24 (GPIO18)
/k30: K30.1, U2.21 (GPIO16)
/k31: K31.1, U2.19 (GPIO14)
/k32: K32.1, U2.20 (GPIO15)
GND: J1.3 (RING1), K00.2, K01.2, K02.2, K03.2, K04.2, K05.2, K10.2, K11.2, K12.2, K13.2, K14.2, K15.2, K20.2, K21.2, K22.2, K23.2, K24.2, K25.2, K30.2, K31.2, K32.2, R2.2, U2.3 (GND), U2.8 (GND), U2.13 (GND), U2.18 (GND), U2.23 (GND), U2.28 (GND), U2.33 (AGND), U2.38 (GND)
VBUS: R1.1, U2.40 (VBUS)
VCC: J1.2 (TIP), U2.39 (VSYS)
rx: J1.4 (RING2), U2.2 (GPIO1)
tx: J1.1 (SLEEVE), U2.1 (GPIO0)
vbus_sense: R1.2, R2.1, U2.34 (GPIO28_ADC2)

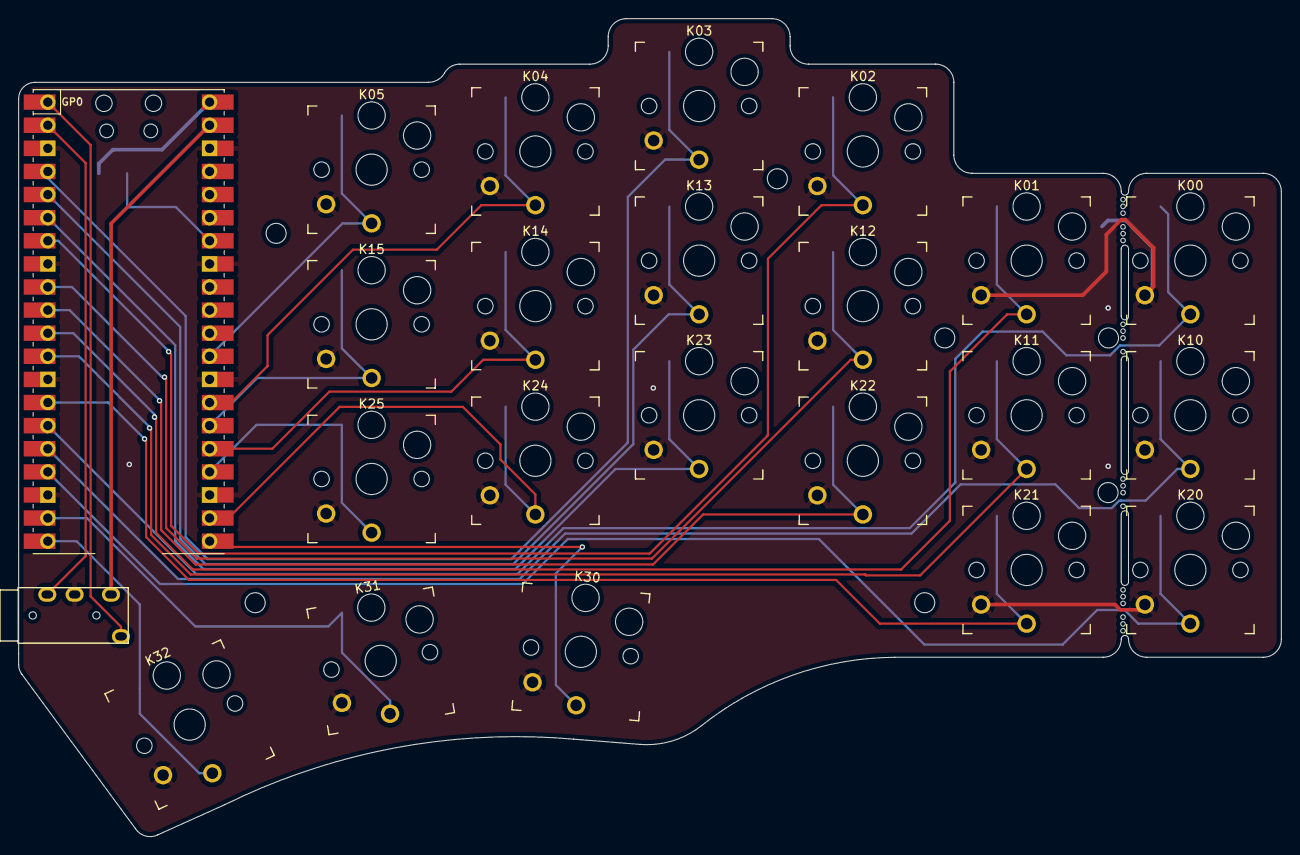
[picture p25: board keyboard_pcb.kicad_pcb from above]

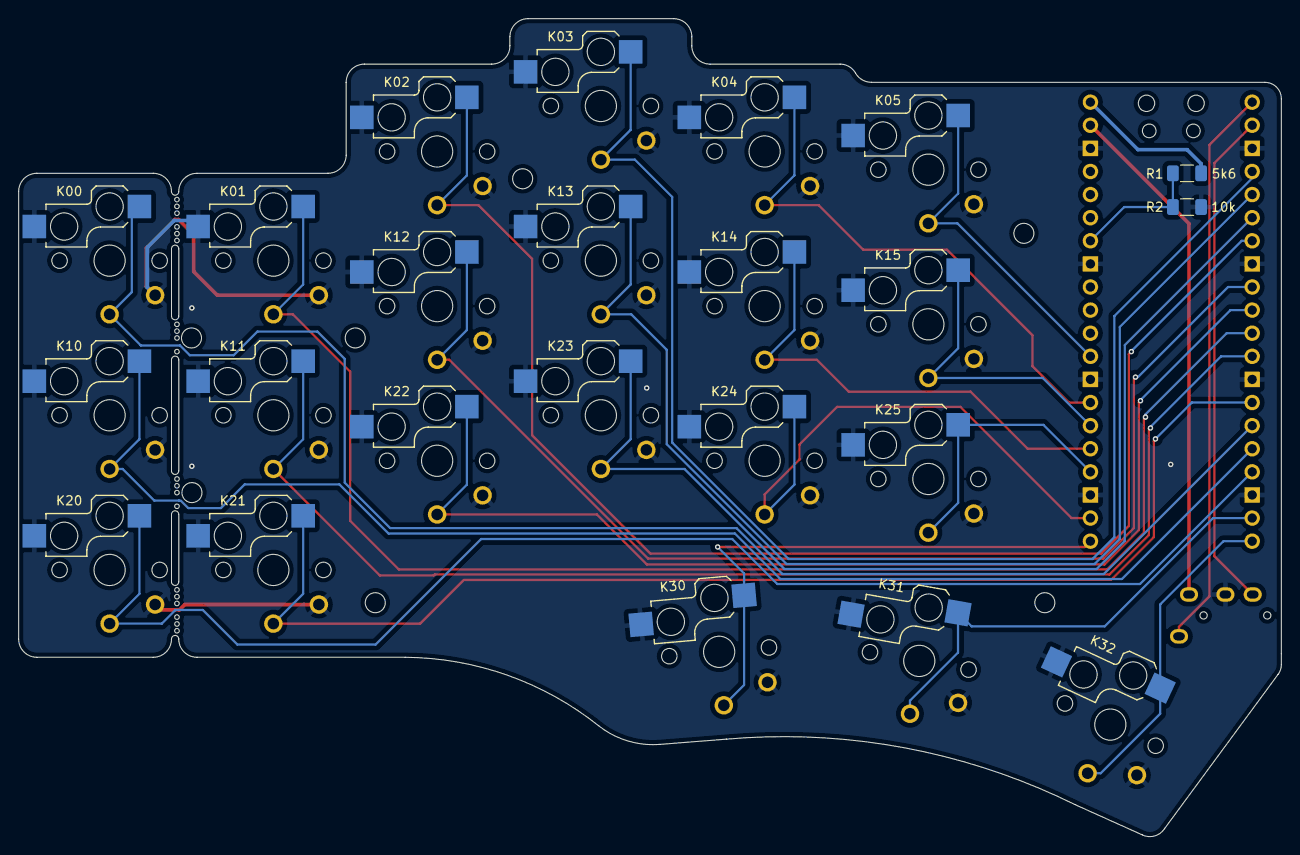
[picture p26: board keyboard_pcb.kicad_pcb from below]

Board: 2 copper layers, 138.8 x 89.9 mm, 36 parts (13 on the bottom side), 27 nets.

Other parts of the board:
H1#2, H4#2, H4#3: MountingHole; MountingHole_2.2mm_M2-8mm

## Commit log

2026-03-01 routing in progress
    [oled_keyboard.kicad_pcb, oled_keyboard.kicad_sch]
2026-03-01 routing ok. added gitignore
    [oled_keyboard.kicad_pcb, oled_keyboard.kicad_sch]
2026-03-03 adjusted silkscreen
    [oled_keyboard.kicad_pcb]
2026-03-03 added test points
    [oled_keyboard.kicad_pcb, oled_keyboard.kicad_sch]
2026-05-24 chged to 9 oled. fixed pin inversion issue
    [oled_keyboard.kicad_pcb, oled_keyboard.kicad_sch]
2026-05-25 optimized key layout
    [oled_keyboard.kicad_pcb, oled_keyboard.kicad_sch]
2026-06-23 fix: added 3v3! enlarged holes for passing naps
    [oled_keyboard.kicad_pcb, oled_keyboard.kicad_sch]
2026-06-23 released v3.1
    [oled_keyboard.kicad_pcb]
2026-07-14 feat: changed fpc connectors
    [2-1734742-0.step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]
2026-07-16 release v4.0
    [oled_keyboard-B_Cu.gbr, oled_keyboard-B_Mask.gbr, oled_keyboard-B_Paste.gbr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]
2026-09-15 release v5.2
    [Assem1.SLDASM, Choc_Stem_Choc_Size_Normal_Homing.step, SN74LVC125ADTG4.step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]

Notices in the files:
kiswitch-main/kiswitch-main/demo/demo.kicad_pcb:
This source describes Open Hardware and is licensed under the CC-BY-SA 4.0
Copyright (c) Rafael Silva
